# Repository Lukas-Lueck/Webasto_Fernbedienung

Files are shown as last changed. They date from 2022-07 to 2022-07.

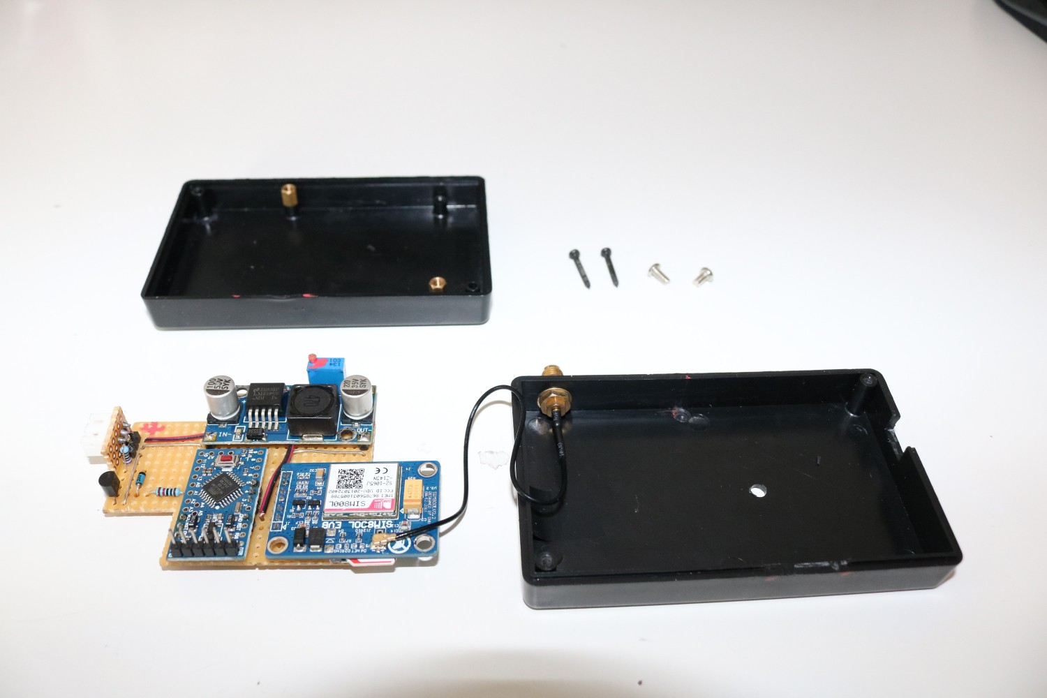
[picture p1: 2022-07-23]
Bauzustand01.jpg

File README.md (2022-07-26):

# Webasto GSM-Fernbedienung

Dies ist ein kleines Projekt, was ich vor ein paar Jahren umgesetzt habe. Gesteuert wird eine Webasto Thermo Top Evo 5, sollte allerdings mit allen anderen Standheizungen auch funktionieren, da nur der "Tastendruck" an der Controlunit simuliert wird. 

## Funktion
Es handelt sich um ein arduino-gesteuertes GSM-Fernbedienungsmodul, welches über eine Signalleitung die Multicontroleinheit einer Webasto Standheizung steuert.

Wird das Modul von einer im Code festgelegten Nummer angerufen, wird zur Bestätigung der Anruf kurz angenommen und nach einer Sekunde wieder aufgelegt. Danach wird die Standheizung ein- oder ausgeschalten, je nach vorherigem Schaltzustand. Unbekannte Nummern werden einfach abgewiesen. Die Heizzeit und der Heizungsmodus muss vorher in der Controllunit festgelegt werden.

## Einbau
Angeklemmt wird das Modul im Fzg. auf Klemme 30 und 31, die Signalleitung des Moduls muss in der Controlunit verlötet werden. Den Lötpunkt bitte messtechnisch ermitteln, direkt an der Heiztaste der Controlleinheit. Dafür muss das Gehäuse geöffnet werden. Die Signalleitung kann über den Diagnoseingang aus dem Gehäuse geführt werden. 
Bei meinem Fzg. habe ich bei verbautem Modul einen Ruhestrom von 84 mA. (mit ausgelöteten Kontroll-LED's vom Arduino/GSM-Shield).

Hinweis: Das Verbauen und Betreiben des Moduls im Fahrzeug erfolgt auf eigene Verantwortung! Ich übernehme keinerlei Haftung für evlt. auftretende (Personen-)Schäden.

## Lizenz

[MIT](LICENSE.md)

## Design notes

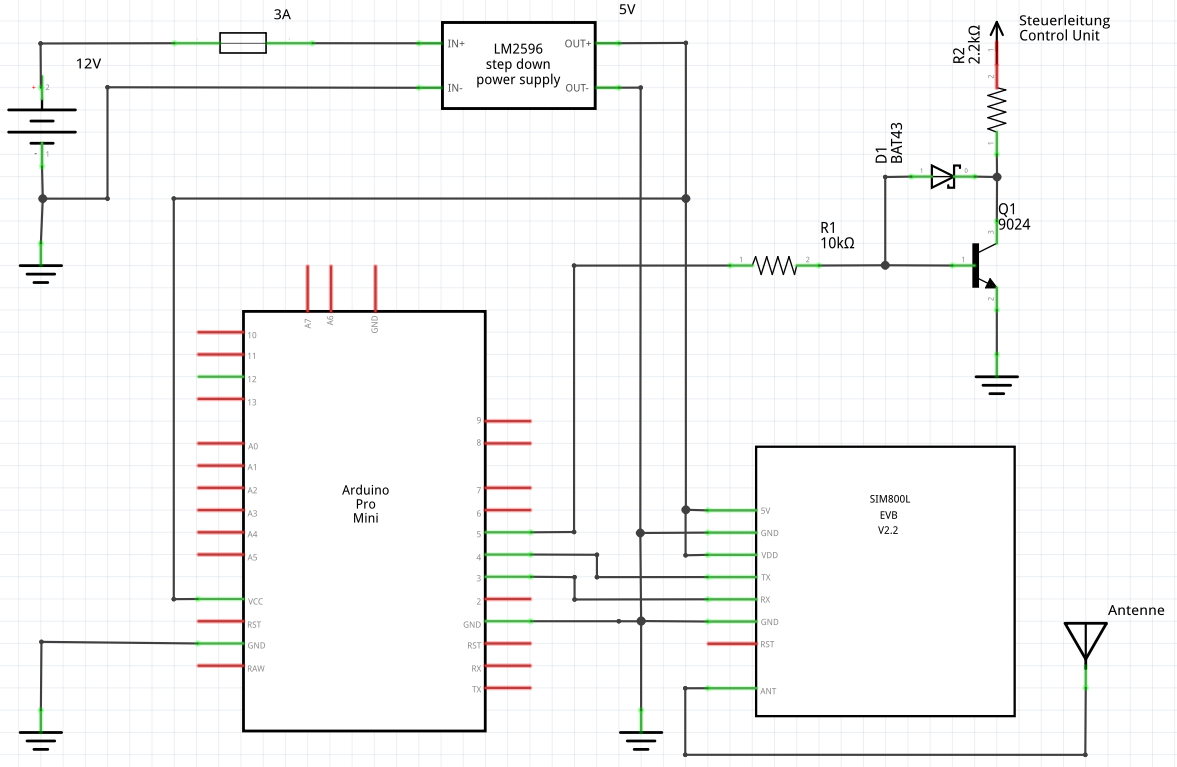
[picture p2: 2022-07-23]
Schaltplan/Schaltplan.tif

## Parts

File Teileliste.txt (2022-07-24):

- Step-Down Modul LM2596 (oder ähnlich, Anforderung: 12V-> 5V, min. 2,5A)
- Arduino Pro mini, 5V-Version
- SIM800L EVB 2.2
- Lochrasterplatine
- GSM-Antenne (für Einbau in Fzg. idealerweise Klebeantenne
- Gehäuse
- Prepaid SIM-Karte, Vodafone empfohlen
- Widerstände: 10kOhm; 2,2kOhm
- Transistor 9024 oder ähnlich, ggf. Widerstände anpassen
- Shotkydiode BAT43 (Schaltcharakteristik des Transistors wird verbessert)
- Steckverbindung, Kabel, Sicherung (5A)

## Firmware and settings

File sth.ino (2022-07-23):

/*
 * GSM-Fernbedienungstool für Webasto Thermo Top Evo 5 mit Multicontroleinheit
 * SIM800L Tx -> PIN #4 Arduino Mini
 *         Rx -> PIN #3 Arduino Mini
 * Arduino Mini PIN #5: Signalleitung an Webasto Multicontroleinheit
 * 
 * verwendeter AT-Befehlssatz:
 * ATV0 = Rückmeldung bei Anruf über Serielle Schnittstelle als Ziffer, 2 = Anruf
 * ATA  = Anruf annehmen
 * ATH  = Anruf beenden
 * 
 * by Lukas Lueck, 01.2021
*/

#include <SoftwareSerial.h>

#define TX 3
#define RX 4

SoftwareSerial gsm(TX,RX);      //Serielle Kommunikation an PIN #3(TX) und PIN #4(RX)

void anrufAuswerten();


char gsmStatus=0;              //aktueller Status, 0 = Leerlauf, 2 = Anruf


void setup()
{
  delay(1000);
  gsm.begin(9600);
  while(!gsm);                  // warten bis SIM800L bereit
  gsm.println("ATV0");
  pinMode(5, OUTPUT);
  digitalWrite(5,LOW);
}  


void loop()
{
  if(gsm.available()>0)         //serielle Schnittstelle aktiv
  { 
    gsmStatus=gsm.read(); 
    if(gsmStatus=='2')
    {
      anrufAuswerten(); 
      gsmStatus='0';
    }
  }
}

void anrufAuswerten()
{
  String buffer=gsm.readString();
  String nummer=buffer.substring(10,23);                       //Telefonnummer auslesen
  if(nummer=="+49XXXXXXXXX" || nummer=="+49XXXXXXXXXXX")
  {
    digitalWrite(5,HIGH);
    delay(300);
    digitalWrite(5,LOW);
    gsm.println("ATA");
    delay(1000);
    gsm.println("ATH");
  }
  else
    gsm.println("ATH");
  nummer="";                                                 //ausgelesene Telefonnummer reseten
}
